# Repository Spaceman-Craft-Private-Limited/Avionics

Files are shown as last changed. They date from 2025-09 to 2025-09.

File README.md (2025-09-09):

Here the explanation of the uploaded .ino files content.
1. 80kv_BLDC.ino - In this file the code is written for a 80kv BLDC motor controlled by a 7Semi BLDC Motor Driver using ESP32 Dev kit.
The GPIO pin connections from 7semi BLDC driver to ESP32 are mentioned in the Code itself as Commented line.
2. all_in_one-damper_repulsion.ino - In this file the code is written for whole the prototype circuit, and in this file two types of code were written.
The first type is written that the stepper motor is controlled by the TB6600 motor driver and the whole code is commented.
The Second type is the code that the stepper motor is controlled by A4988 stepper motor driver and the whole code uncommented.
All the circuit connection is mentioned in the code itself and the Microcontroller used for this whole system is ESP32 Dev kit.
3. small_prototype_system_code_70rpm_noattraction.ino -  In this file the code is written to control the stepper motor by A4988 motor driver using Arduino uno microcontroller.
The term noattraction means the relay is always on, So the electromagnet connected in relay is always energized.
All the pins configurations are mentioned in the code itself.
4. small_prototype_system_code_70rpm_withattraction.ino - In this file the code is written to control the stepper motor by A4988 motor driver using Arduino uno microcontroller.
The term withattraction means the relay will turn on for few sec and turn off based on the logic given in code, So the electromagnet connected in relay will energized based on time.
All the pins configurations are mentioned in the code itself.

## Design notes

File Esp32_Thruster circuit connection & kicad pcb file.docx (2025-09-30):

ESP32_THRUSTER_CIRCUIT CONNECTION AND KICAD FILE

Circuit connection:

Esp32:

- Connect VIN pin to 5V from the power source.
- Connect GND pin to -ive from the power source.

Esp32 to A4988:

- Connect 3V3 pin to the VDD of A4988.
- Connect GND pin to the GND of A4988.
- Connect 3V3 pin to the SLEEP & RESET pin of A4988.
- Connect the D19 pin to the DIR pin of A4988.
- Connect the D18 pin to the STEP pin of A4988.
- Connect the D21 pin to the ENABLE pin of A4988.

A4988:

- Connect the VMOT pin to 12V from the power source.
- Connect the GND pin to -ive pin from the power source.
- Connect the 1A, 1B, 2A, 2B coil pins to the Stepper motor.
- Remaining pins connect as it from the Esp32 to A4988 titled.

BTS7096 H- Bridge to Esp32:

- Connect the VCC pin to the 3V3 pin of the Esp32.
- Connect the GND pin to the GND pin of the Esp32.
- Connect the R_EN & L_EN pin to the 3V3 pin of the Esp32.
- Connect the RPWM pin to the D15 pin of the Esp32.
- Connect the LPWM pin to the D23 pin of the Esp32.

BTS7096 H- Bridge:

- Connect the Screw pins B+ and B- to the external power source for Eddy damper.
- Connect the Screw pins M+ and M- to the Eddy damper coil terminals.

Relay module:

- Connect the RELAY_SIGNAL pin to the BASE of 2N2222A Transistor via 1k ohm Resistance to Esp32 pin of D22.
- Connect the EMITTER pin of 2N2222A Transistor to the GND pin of Esp32.
- Connect the COLLECTOR pin of 2N2222A Transistor to the Relay coil which is GND.
- Connect the VCC pin of Relay to VIN pin of Esp32.

DC-DC Buck Boosters:

- Two Buck Boosters has been used in this circuit.
- One buck booster is used as power source of Esp32 and Relay, it converts 12V DC to 5V DC.
- Another Buck Booster is used as power source for Eddy damper to increase the power of Eddy current, it connects in the B+ and B- pins of the BTS7096 H- Bridge module.

Links:

- The Code link is upload in the Github repository: https://github.com/Spaceman-Craft-Private-Limited/Avionics/blob/1c2c8f235eef1a50a3d4c8d4f2fde9fde5429fe6/all_in_one-dmaper_repulsion.ino
- The PCB Design link: https://github.com/Spaceman-Craft-Private-Limited/Avionics

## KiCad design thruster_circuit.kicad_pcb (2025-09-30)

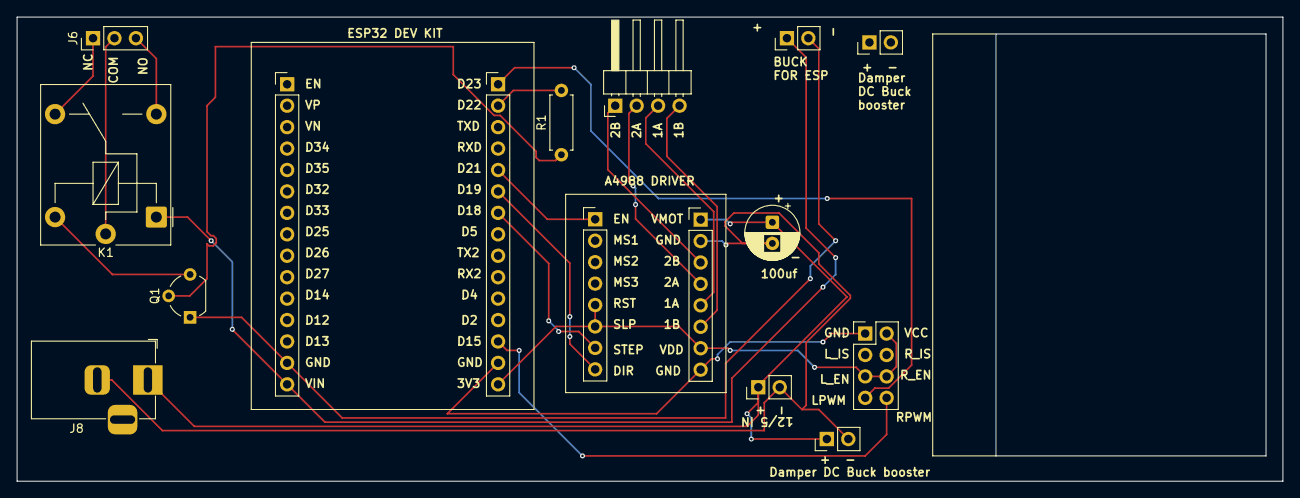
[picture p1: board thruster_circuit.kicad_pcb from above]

Board: 2 copper layers, 150.0 x 55.0 mm, 16 parts (0 on the bottom side), 21 nets.

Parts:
C1: C; CP_Radial_D6.3mm_P2.50mm
J1, J2: Conn_01x15; PinHeader_1x15_P2.54mm_Vertical
J3, J4: Conn_01x08; PinHeader_1x08_P2.54mm_Vertical
J5: Conn_01x04; PinHeader_1x04_P2.54mm_Horizontal
J6: Conn_01x03; PinHeader_1x03_P2.54mm_Vertical
J7, J9, J10, J11: Conn_01x02; PinHeader_1x02_P2.54mm_Vertical
J8: Barrel_Jack; BarrelJack_Horizontal
J12: Conn_02x04_Top_Bottom; PinHeader_2x04_P2.54mm_Vertical
K1: Relay_SPDT; Relay_SPDT_Finder_36.11
Q1: 2N3904; TO-92_Wide
R1: R; R_Axial_DIN0207_L6.3mm_D2.5mm_P7.62mm_Horizontal

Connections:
unnamed: J1.14, J7.2, Q1.1 (E)
unnamed: J1.15, J7.1, K1.A1
unnamed: J2.2, R1.2
unnamed: J2.5, J3.1
unnamed: J2.6, J3.8
unnamed: J2.7, J3.7
unnamed: J4.3, J5.1
unnamed: J4.4, J5.2
unnamed: J4.5, J5.3
unnamed: J4.6, J5.4
unnamed: J6.1, K1.12
unnamed: J6.2, K1.11
unnamed: J6.3, K1.14
unnamed: C1.1, J4.1, J8.1, J9.1, J10.1
unnamed: C1.2, J4.2, J8.2, J9.2, J10.2
unnamed: J2.14, J4.8, J12.1
unnamed: J2.15, J3.5, J3.6, J4.7, J12.2, J12.5, J12.6
unnamed: J2.1, J12.7
unnamed: J2.13, J12.8
unnamed: Q1.2 (B), R1.1
unnamed: K1.A2, Q1.3 (C)

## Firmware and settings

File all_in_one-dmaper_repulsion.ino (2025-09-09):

// // code with tb6600 whole system-------------------------
// #include <Arduino.h> // Core ESP32 functions
// #include <AccelStepper.h> // Library for stepper motor control

// // --- Pin Definitions ---
// #define STEP_PIN 18      // GPIO for stepper motor PUL+ signal (TB6600 PUL pin)
// #define DIR_PIN 19       // GPIO for stepper motor DIR+ signal (TB6600 DIR pin)
// #define ENABLE_PIN 21    // GPIO for TB6600 EN+ pin (active LOW)
// #define RELAY_PIN 22     // GPIO for the relay control signal (connects to NPN transistor base)

// // --- BTS7960 H-Bridge Pins for Eddy Damper Coil ---
// // Connect these to the corresponding pins on your BTS7960 module
// #define RPWM_PIN 15      // Right PWM input (e.g., IN_R or RPWM)
// #define LPWM_PIN 23      // Left PWM input (e.g., IN_L or LPWM)
// // R_EN and L_EN are typically tied HIGH on the module itself or connected to a GPIO if you need to enable/disable
// // For continuous operation, we'll assume they are enabled.

// // --- Motor Configuration ---
// #define MOTOR_INTERFACE_TYPE 1 // Motor interface type: 1 = Driver (STEP/DIR)
// const int STEPS_PER_REVOLUTION = 1600; // STEPS_PER_REVOLUTION for 1/8 micro-stepping (200 steps/rev * 8)

// // Create stepper object: (interface type, step pin, direction pin)
// AccelStepper stepper(MOTOR_INTERFACE_TYPE, STEP_PIN, DIR_PIN);

// // --- Motor Speed Variables ---
// const float TARGET_MOTOR_RPM = 100.0; // Target RPM for continuous motor movement
// float motorSpeedStepsPerSec;          // Calculated speed in steps/second

// // --- Relay Control Variables (Non-blocking with millis()) ---
// unsigned long previousRelayMillis = 0;    // Stores when the relay last changed state
// unsigned long relayOnDuration = 1000;     // Relay ON for 1 second
// unsigned long relayOffDuration = 2000;    // Relay OFF for 2 seconds
// bool relayState = false;                  // Current state of the relay (false = OFF, true = ON)

// // --- Eddy Damper Bidirectional Toggle Configuration (25 Hz - 20ms in one direction / 20ms in other) ---
// unsigned long previousDamperToggleMillis = 0; // Stores when the eddy damper direction last changed
// const unsigned long damperDirectionDuration = 20; // Time for current in one direction (20ms)
// bool currentDirectionState = false;           // false = Direction 1 (RPWM HIGH), true = Direction 2 (LPWM HIGH)


// void setup() {
//   // --- Start Serial Communication Early for Debugging ---
//   Serial.begin(115200);
//   Serial.println("\n--- System Booting Up ---");

//   // --- Initial Delay to Ensure ESP32 Stability ---
//   delay(100); // Small delay to allow ESP32 to stabilize

//   Serial.println("ESP32 TB6600 Continuous Motor (100 RPM) with Non-Blocking Relay & BTS7960 Eddy Damper Started!");
//   Serial.println("Eddy Damper is driven by BTS7960 with 20ms in one direction, then 20ms in the other (25Hz alternating).");

//   // --- Initialize TB6600 Driver Pins ---
//   pinMode(ENABLE_PIN, OUTPUT);
//   digitalWrite(ENABLE_PIN, LOW); // Enable the TB6600 motor driver (LOW = enabled)
//   pinMode(DIR_PIN, OUTPUT);
//   digitalWrite(DIR_PIN, HIGH); // Set initial direction to clockwise

//   // --- Initialize Relay Pin (for NPN transistor base) ---
//   pinMode(RELAY_PIN, OUTPUT);
//   digitalWrite(RELAY_PIN, LOW); // Initially turn transistor OFF -> relay OFF

//   // --- Initialize BTS7960 H-Bridge Pins ---
//   pinMode(RPWM_PIN, OUTPUT);
//   pinMode(LPWM_PIN, OUTPUT);

//   // Start with current in one direction (e.g., RPWM HIGH, LPWM LOW)
//   digitalWrite(RPWM_PIN, HIGH);
//   digitalWrite(LPWM_PIN, LOW);
//   currentDirectionState = false; // Set initial state
//   Serial.println("Eddy Damper initialized with current in one direction.");

//   // --- AccelStepper Configuration ---
//   motorSpeedStepsPerSec = (STEPS_PER_REVOLUTION * TARGET_MOTOR_RPM) / 60.0;
//   stepper.setMaxSpeed(motorSpeedStepsPerSec);
//   stepper.setAcceleration(0); // No acceleration for continuous rotation
//   stepper.setSpeed(motorSpeedStepsPerSec);
// }

// void loop() {
//   // --- Stepper Motor Control (Continuous 100 RPM) ---
//   stepper.runSpeed();

//   // --- Non-Blocking Relay Logic ---
//   unsigned long currentMillis = millis();
//   if (relayState) {
//     if (currentMillis - previousRelayMillis >= relayOnDuration) {
//       relayState = false;
//       digitalWrite(RELAY_PIN, LOW); // Turn transistor OFF -> relay OFF
//       previousRelayMillis = currentMillis;
//       Serial.println("Relay OFF");
//     }
//   } else {
//     if (currentMillis - previousRelayMillis >= relayOffDuration) {
//       relayState = true;
//       digitalWrite(RELAY_PIN, HIGH); // Turn transistor ON -> relay ON
//       previousRelayMillis = currentMillis;
//       Serial.println("Relay ON");
//     }
//   }

//   // --- Non-Blocking Eddy Damper Bidirectional Toggle Logic (20ms per direction) ---
//   if (currentMillis - previousDamperToggleMillis >= damperDirectionDuration) {
//     if (currentDirectionState == false) {
//       // Switch to Direction 2: LPWM HIGH, RPWM LOW
//       digitalWrite(RPWM_PIN, LOW);
//       digitalWrite(LPWM_PIN, HIGH);
//       currentDirectionState = true;
//       // Serial.println("Eddy Damper Direction 2"); // Uncomment for verbose debugging
//     } else {
//       // Switch to Direction 1: RPWM HIGH, LPWM LOW
//       digitalWrite(RPWM_PIN, HIGH);
//       digitalWrite(LPWM_PIN, LOW);
//       currentDirectionState = false;
//       // Serial.println("Eddy Damper Direction 1"); // Uncomment for verbose debugging
//     }
//     previousDamperToggleMillis = currentMillis; // Reset the timer
//   }
// }

// code with A4988 driver -----------------------------
#include <Arduino.h>
#include <AccelStepper.h> 

// --- Pin Definitions ---
#define STEP_PIN 18     
#define DIR_PIN 19      
#define ENABLE_PIN 21   

#define RELAY_PIN 22    
#define RPWM_PIN 15      
#define LPWM_PIN 23      

// --- Motor Configuration ---
#define MOTOR_INTERFACE_TYPE 1   // DRIVER mode for A4988
const int STEPS_PER_REVOLUTION = 200; // Full-step mode

AccelStepper stepper(MOTOR_INTERFACE_TYPE, STEP_PIN, DIR_PIN);

// --- Motor Speed Variables ---
const float TARGET_MOTOR_RPM = 100.0; 
float motorSpeedStepsPerSec;       

// --- Relay Control Variables ---
unsigned long previousRelayMillis = 0;   
unsigned long relayOnDuration = 1000;    // 1 sec ON
unsigned long relayOffDuration = 2000;   // 2 sec OFF
bool relayState = false;             

// --- Eddy Damper Bidirectional Toggle ---
unsigned long previousDamperToggleMillis = 0; 
const unsigned long damperDirectionDuration = 20; 
bool currentDirectionState = false;          

void setup() {
  Serial.begin(115200);
  Serial.println("\n--- System Booting Up ---");
  delay(100); 

  Serial.println("ESP32 A4988 Continuous Motor (100 RPM) with Non-Blocking Relay & BTS7960 Eddy Damper Started!");

  // --- Initialize A4988 Driver Pins ---
  pinMode(ENABLE_PIN, OUTPUT);
  digitalWrite(ENABLE_PIN, LOW); // LOW = enabled
  pinMode(DIR_PIN, OUTPUT);
  digitalWrite(DIR_PIN, HIGH); 
  
  // --- Initialize Relay & BTS7960 Pins ---
  pinMode(RELAY_PIN, OUTPUT);
  digitalWrite(RELAY_PIN, LOW); 
  pinMode(RPWM_PIN, OUTPUT);
  pinMode(LPWM_PIN, OUTPUT);
  digitalWrite(RPWM_PIN, HIGH);
  digitalWrite(LPWM_PIN, LOW);
  currentDirectionState = false; 
  Serial.println("Eddy Damper initialized with current in one direction.");

  // --- AccelStepper Configuration ---
  motorSpeedStepsPerSec = (STEPS_PER_REVOLUTION * TARGET_MOTOR_RPM) / 60.0; // 200*100/60 = ~333 steps/sec
  stepper.setMaxSpeed(1000);      // allow up to 1000 steps/sec
  stepper.setAcceleration(500);   // smooth acceleration
  stepper.setSpeed(motorSpeedStepsPerSec); // constant speed
}

void loop() {
  // --- Stepper Motor Continuous Rotation ---
  stepper.runSpeed();

  // --- Non-Blocking Relay Logic ---
  unsigned long currentMillis = millis();
  if (relayState) {
    if (currentMillis - previousRelayMillis >= relayOnDuration) {
      relayState = false;
      digitalWrite(RELAY_PIN, LOW); 
      previousRelayMillis = currentMillis;
      Serial.println("Relay OFF");
    }
  } else {
    if (currentMillis - previousRelayMillis >= relayOffDuration) {
      relayState = true;
      digitalWrite(RELAY_PIN, HIGH); 
      previousRelayMillis = currentMillis;
      Serial.println("Relay ON");
    }
  }

  // --- Non-Blocking Eddy Damper Bidirectional Toggle ---
  if (currentMillis - previousDamperToggleMillis >= damperDirectionDuration) {
    if (currentDirectionState == false) {
      digitalWrite(RPWM_PIN, LOW);
      digitalWrite(LPWM_PIN, HIGH);
      currentDirectionState = true;
    } else {
      digitalWrite(RPWM_PIN, HIGH);
      digitalWrite(LPWM_PIN, LOW);
      currentDirectionState = false;
    }
    previousDamperToggleMillis = currentMillis;
  }
}

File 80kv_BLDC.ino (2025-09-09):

#include <SimpleFOC.h>

// BLDC motor instance (14 pole pairs typical for 2208 motors, verify with datasheet)
BLDCMotor motor = BLDCMotor(14);

// 6 PWM driver for TMC6300
BLDCDriver6PWM driver = BLDCDriver6PWM(26, 27, 14, 12, 13, 15); // UH, UL, VH, VL, WH, WL

void setup() {
  // Initialize driver
  driver.voltage_power_supply = 10.36; // Set to your supply voltage
  driver.init();
  motor.linkDriver(&driver);

  // Set control mode to open-loop velocity
  motor.controller = MotionControlType::velocity_openloop;
  motor.voltage_limit = 10.36; // Match supply voltage
  motor.velocity_limit = 50; // Limit max speed (rad/s)

  // Initialize motor
  motor.init();

  Serial.begin(115200);
  Serial.println("Motor ready!");
}

void loop() {
  motor.loopFOC(); // Run commutation logic
  motor.move(20.94); // Target 200 RPM
}
